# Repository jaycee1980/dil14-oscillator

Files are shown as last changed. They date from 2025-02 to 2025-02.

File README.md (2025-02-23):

# dil14-oscillator
A DIL-16 oscillator using a 3.2x2.5mm SMD crystal. Originally I made this for Commodore Amigas, because the 28.6363MHz and 28.37516MHz oscillators are becoming hard to get. Most modern oscillators now are 3.3V types

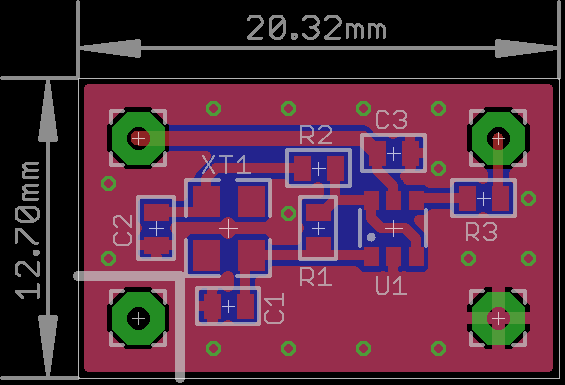
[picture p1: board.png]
Image of the PCB


I found that while they're not common, it IS possible to get crystals of those frequencies in SMD format. For example Mouser have [CTS 403C35D28M37500](https://www.mouser.co.uk/ProductDetail/CTS-Electronic-Components/403C35D28M37500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) and [ECS 520-286.3-18-33-JGNT](https://www.mouser.co.uk/ProductDetail/ECS/ECS-286.3-18-33-JGN-TR?qs=wd5RIQLrsJjqi%252B%2F66hueEA%3D%3D). These are suitable for use with an Amiga, but they need an oscillator circuit to work. This was easily achievable with the usual Pierce oscillator configuration using logic gates. 

I chose to use a "picogate" type part to keep the size small, the 74LVC2GU04. This is a SOT23-6 part (aka SOT457 o TSOP6) and perfect for the job. 

I've also found that LCSC have suitable crystals in their inventory. They are:

https://www.lcsc.com/product-detail/Crystals_TXC-Corp-7V-28-63636MAHJ-T_C2595058.html

https://www.lcsc.com/product-detail/Crystals_YXC-Crystal-Oscillators-X322528375MSB4SI_C20618000.html

# Whats in this repo? 

In here you can find EAGLE 7.6 board and schematic, Gerber files for manufacture, and BOM + CPL files suitable for use with [JLCPCB](https://jlcpcb.com)

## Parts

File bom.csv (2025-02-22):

Comment | Designator | Footprint | LCSC Part #
18p | C1 C2 | 0603 | C1647
100n | C3 | 0603 | C14663
1M | R1 | 0603 | C22935
220 | R2 | 0603 | C22962
22 | R3 | 0603 | C23345
SN74LVC2GU04DBVR | U1 | SOT-23-6 | C139427
28.375MHz | XT1 | 3225 | C20618000

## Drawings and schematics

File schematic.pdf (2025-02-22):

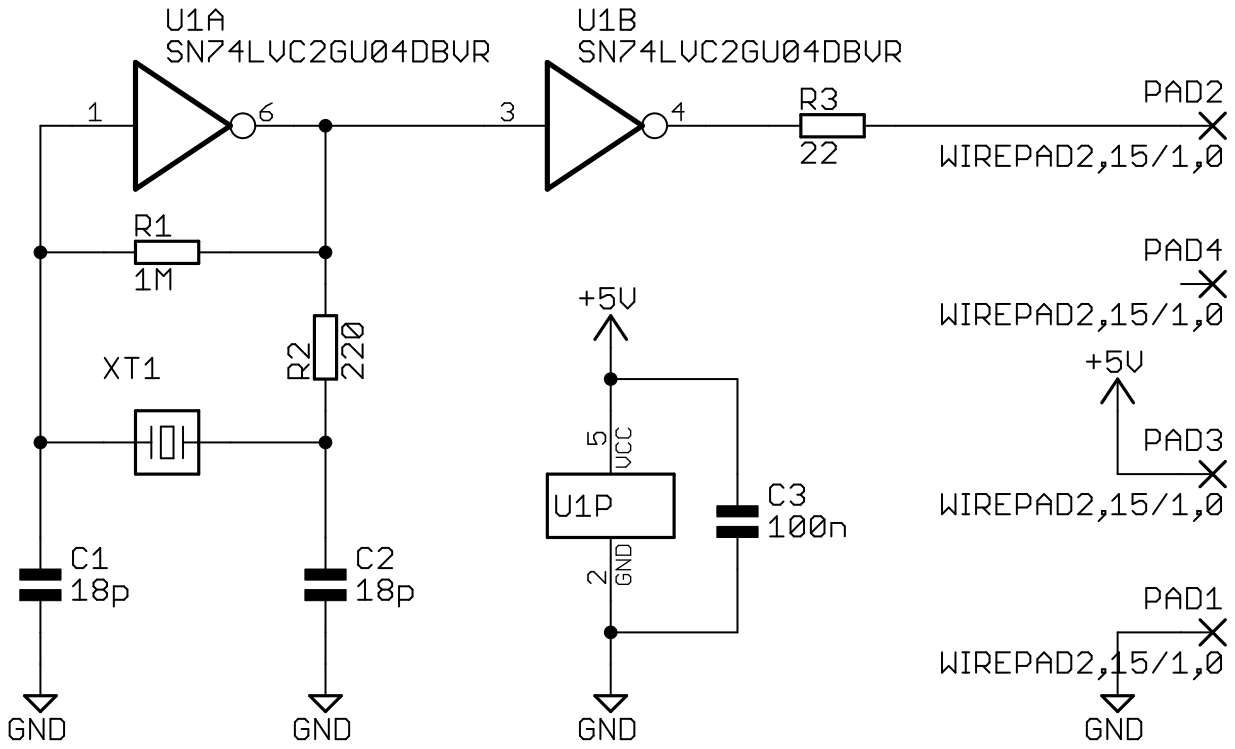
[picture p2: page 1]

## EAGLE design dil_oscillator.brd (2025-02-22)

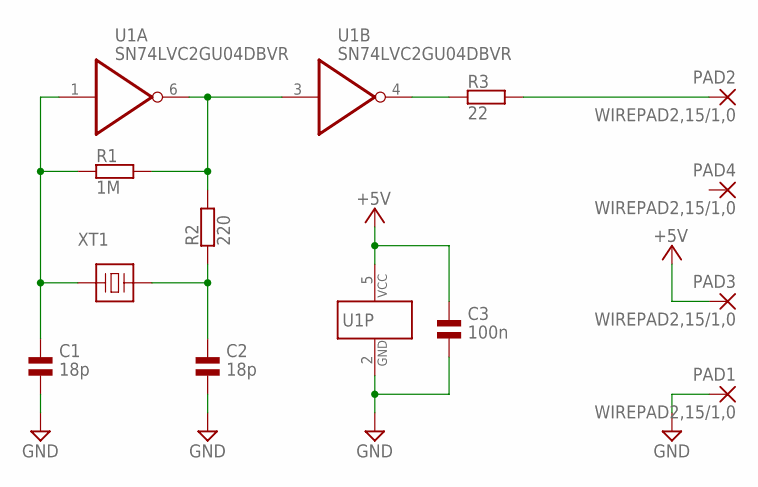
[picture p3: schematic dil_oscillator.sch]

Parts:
C1, C2: 18p; 0603
C3: 100n; 0603
PAD1, PAD2, PAD3, PAD4: WIREPAD2,15/1,0; 2,15/1,0
R1: 1M; 0603
R2: 220; 0603
R3: 22; 0603
U1: SN74LVC2GU04DBVR; SOT457
XT1: XTAL_3225; 3225_4PAD

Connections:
+5V: C3.1, PAD3.1, U1.5 (VCC)
GND: C1.2, C2.2, C3.2, PAD1.1, U1.2 (GND)
unnamed: C1.1, R1.1, U1.1 (I), XT1.1
unnamed: R1.2, R2.2, U1.3 (I), U1.6 (O)
unnamed: C2.1, R2.1, XT1.3 (2)
unnamed: R3.1, U1.4 (O)
OUT: PAD2.1, R3.2

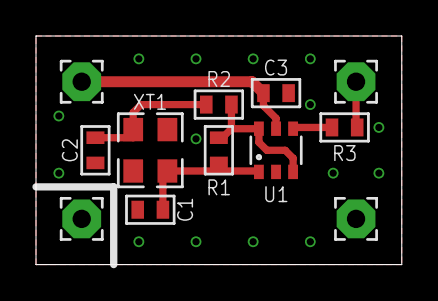
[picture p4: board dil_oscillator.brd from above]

Board: 2 copper layers, 20.3 x 12.7 mm, 12 parts (0 on the bottom side), 7 nets.

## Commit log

2025-02-22 PDF version of schematic
2025-02-23 Added image of the board
